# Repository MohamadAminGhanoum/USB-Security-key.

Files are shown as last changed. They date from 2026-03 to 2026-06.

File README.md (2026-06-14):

# USB-Security-key.
I want to make this key a type-c key, which i can use to log into my computer or account with for better security. (at the end i had to use USB-A)

So i initially started with making this a usb-c security key, because i would be able to use it on all my devices, however, since the thickness of the board would need to be around 1.6 mm, it would cost too much in jlcpcb, therefore i had to disregard this idea, and move to a usb-type a port. I also wanted this to be assembled by jlcpcb, but since the components are on both sides of the board, it would cost approximately 105 usd to only assemble the board. 

Therefore i came with the idea that i would like to use a high melting solder on the side with least components, and the other side, i want to use solder that will melt in the temperature of around 180 degrees.

## Built version:




## 3d-model





## Schematics:



## pcb


## BOM



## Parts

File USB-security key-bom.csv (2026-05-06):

Name | Purpose | Quantity | Total Cost (USD) | Link | Distributor
100nF 50V X7R 0603 | C? | 100 | 0.30
4.7µF 10V X5R 0603 | C? | 10 | 0.10
10µF 10V X5R 0603 | C? | 100 | 0.80
3.3µH Inductor | L? | 100 | 1.70
Power Switching IC | U? | 20 | 0.85
16Mbit SPI Flash | U? | 2 | 2.08
3.3V LDO Regulator | U? | 5 | 1.07
MCU | U? | 2 | 2.48
USB ESD Protection | U? | 10 | 1.52
25MHz Crystal | Y? | 10 | 2.94
10kΩ Resistor 0603 | R? | 100 | 0.15
330Ω Resistor 0603 | R? | 100 | 0.11
100Ω Resistor 0603 | R? | 1 | 0.00
LED / Indicator 0603 | D? | 1 | 0.00
270Ω Resistor 0603 | R? | 100 | 0.30
15pF 50V C0G 0603 | C? | 100 | 2.16
PCB | Board for components | 5 | 3.60 | https://cart.jlcpcb.com/shopcart/cart/ | JLCPCB

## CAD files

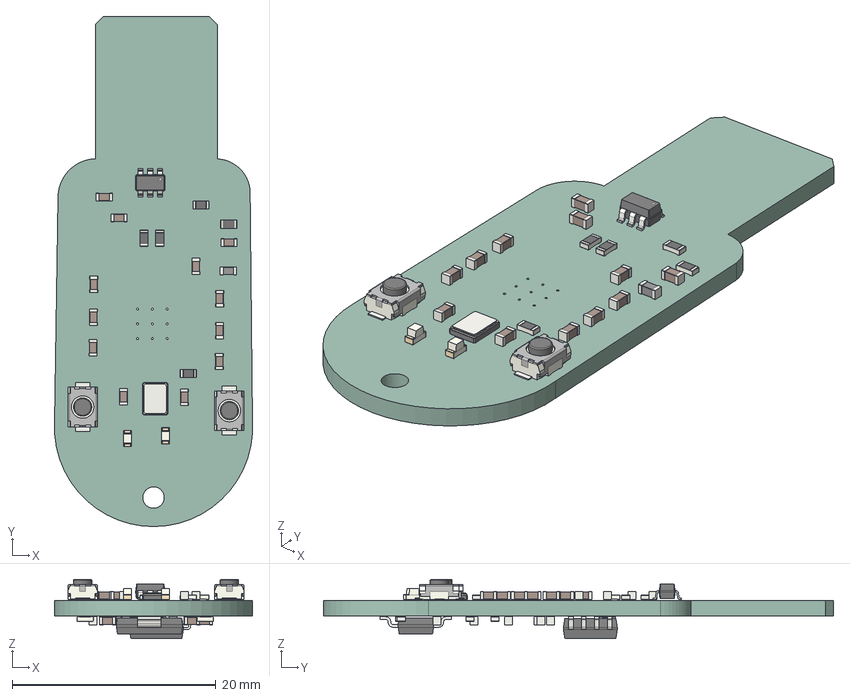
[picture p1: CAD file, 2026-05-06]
USB-C security key.step
19.4 x 50.1 x 5.84 mm
C_0603_1608Metric x 19
LED_0603_1608Metric x 2
R_0603_1608Metric x 9
SOT-23-6
L_0603_1608Metric
Crystal_SMD_3225-4Pin_3.2x2.5mm
SW_Push_SPST_NO_Alps_SKRK x 2
SOT-223
SOIC-8_5.3x5.3mm_P1.27mm
USB-C security key_PCB

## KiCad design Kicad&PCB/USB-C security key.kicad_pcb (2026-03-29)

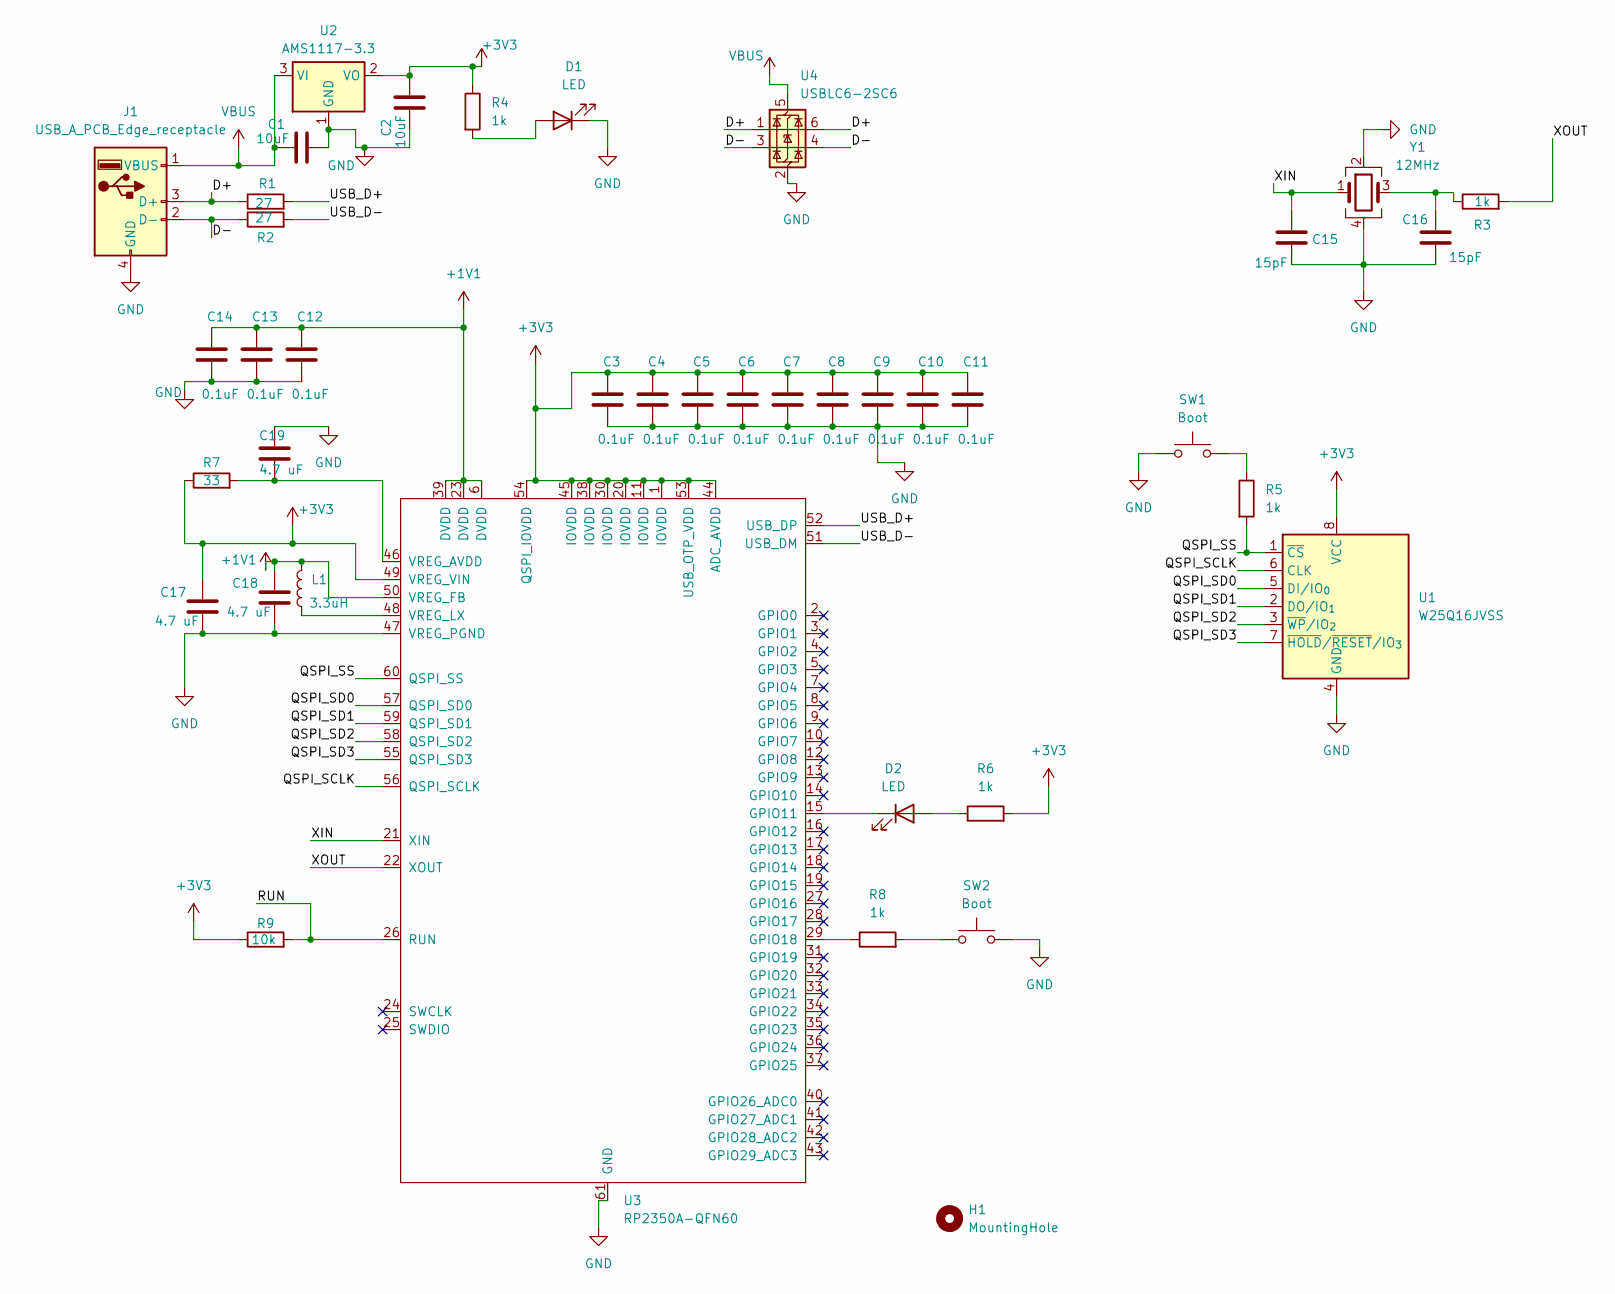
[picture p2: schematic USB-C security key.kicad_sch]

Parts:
C1, C2: 10uF; C_0603_1608Metric
C3, C4, C5, C6, C7, C8, C9, C10, C11, C12, C13, C14: 0.1uF; C_0603_1608Metric
C15, C16: 15pF; C_0603_1608Metric
C17, C18, C19: 4.7 uF; C_0603_1608Metric
D1, D2: LED; LED_0603_1608Metric
H1: MountingHole; MountingHole_2.1mm
J1: USB_A_PCB_Edge_receptacle
L1: 3.3uH; L_0603_1608Metric
R1, R2: 27; R_0603_1608Metric
R3, R4, R5, R6, R8: 1k; R_0603_1608Metric
R7: 33; R_0603_1608Metric
R9: 10k; R_0603_1608Metric
SW1, SW2: Boot; SW_Push_SPST_NO_Alps_SKRK
U1: W25Q16JVSS; SOIC-8_5.3x5.3mm_P1.27mm
U2: AMS1117-3.3; SOT-223-3_TabPin2
U3: RP2350A-QFN60; QFN-60-1EP_7x7mm_P0.4mm_EP3.4x3.4mm_ThermalVias
U4: USBLC6-2SC6; SOT-23-6
Y1: 12MHz; Crystal_SMD_3225-4Pin_3.2x2.5mm

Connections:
+1V1: C12.1, C13.1, C14.1, C18.1, L1.2, U3.6 (DVDD), U3.23 (DVDD), U3.39 (DVDD), U3.50 (VREG_FB)
+3V3: C2.2, C3.1, C4.1, C5.1, C6.1, C7.1, C8.1, C9.1, C10.1, C11.1, C17.1, R4.1, R6.2, R7.1, R9.1, U1.8 (VCC), U2.2 (VO), U3.1 (IOVDD), U3.11 (IOVDD), U3.20 (IOVDD), U3.30 (IOVDD), U3.38 (IOVDD), U3.44 (ADC_AVDD), U3.45 (IOVDD), U3.49 (VREG_VIN), U3.53 (USB_OTP_VDD), U3.54 (QSPI_IOVDD)
/D+: J1.3 (D+), R1.1, U4.1 (I/O1), U4.6 (I/O1)
/D-: J1.2 (D-), R2.1, U4.3 (I/O2), U4.4 (I/O2)
/QSPI_SCLK: U1.6 (CLK), U3.56 (QSPI_SCLK)
/QSPI_SD0: U1.5 (DI/IO_{0}), U3.57 (QSPI_SD0)
/QSPI_SD1: U1.2 (DO/IO_{1}), U3.59 (QSPI_SD1)
/QSPI_SD2: U1.3 (~WP/IO_{2}), U3.58 (QSPI_SD2)
/QSPI_SD3: U1.7 (~HOLD/~RESET/IO_{3}), U3.55 (QSPI_SD3)
/QSPI_SS: R5.2, U1.1 (~CS), U3.60 (QSPI_SS)
/RUN: R9.2, U3.26 (RUN)
/USB_D+: R1.2, U3.52 (USB_DP)
/USB_D-: R2.2, U3.51 (USB_DM)
/XIN: C15.1, U3.21 (XIN), Y1.1
/XOUT: R3.2, U3.22 (XOUT)
GND: C1.2, C2.1, C3.2, C4.2, C5.2, C6.2, C7.2, C8.2, C9.2, C10.2, C11.2, C12.2, C13.2, C14.2, C15.2, C16.2, C17.2, C18.2, C19.1, D1.1 (K), J1.4 (GND), SW1.1, SW2.2, U1.4 (GND), U2.1 (GND), U3.47 (VREG_PGND), U3.61 (GND), U4.2 (GND), Y1.2, Y1.4
unnamed: C16.1, R3.1, Y1.3
unnamed: D1.2 (A), R4.2
unnamed: D2.2 (A), R6.1
unnamed: D2.1 (K), U3.15 (GPIO11)
unnamed: R5.1, SW1.2
unnamed: R8.2, SW2.1
unnamed: R8.1, U3.29 (GPIO18)
unnamed: C19.2, R7.2, U3.46 (VREG_AVDD)
unnamed: L1.1, U3.48 (VREG_LX)
VBUS: C1.1, J1.1 (VBUS), U2.3 (VI), U4.5 (VBUS)

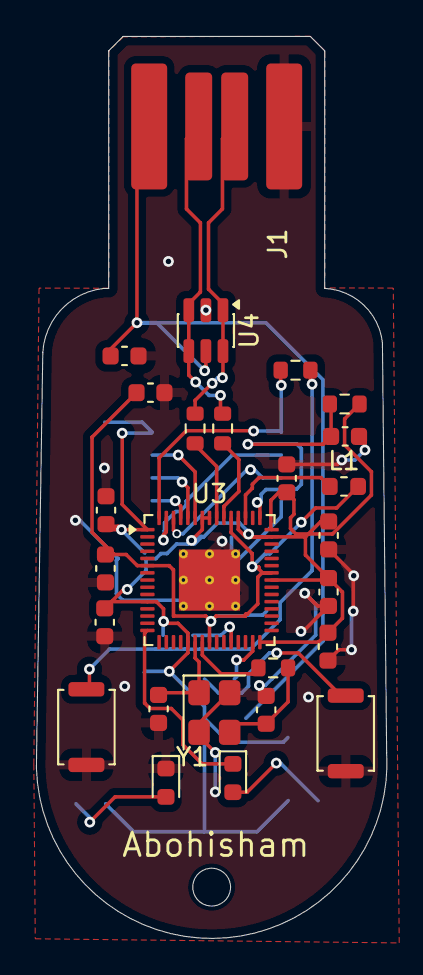
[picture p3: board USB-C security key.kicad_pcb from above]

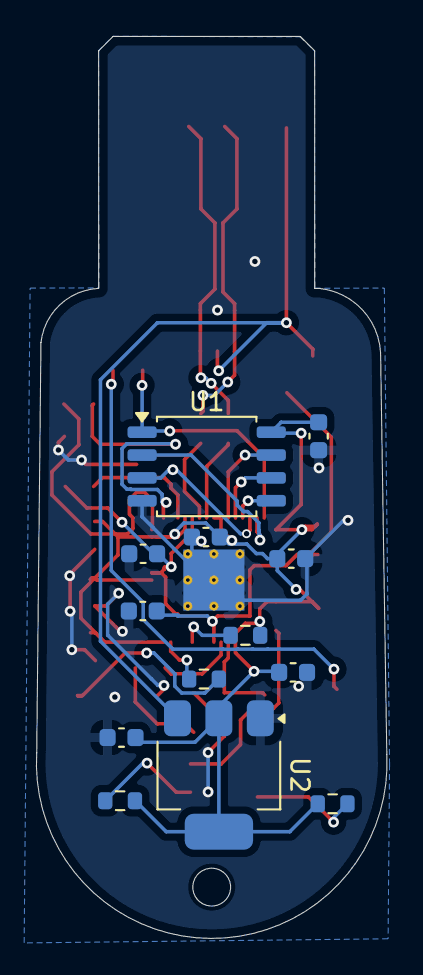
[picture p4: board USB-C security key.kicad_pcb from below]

Board: 2 copper layers, 19.5 x 50.1 mm, 40 parts (13 on the bottom side), 26 nets.
